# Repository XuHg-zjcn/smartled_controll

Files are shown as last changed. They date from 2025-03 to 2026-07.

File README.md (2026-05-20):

# 智能LED控制器
该LED控制器用于吸顶灯、灯带、台灯的控制，使用12-48V电源供电(使用Buck驱动，电源电压必须高于灯的电压)，使用经过编码的RS485通信。计划PCB采用双面板，板上最多可焊4个LED驱动电路
待添加多种设计，分别支持4通道和2通道
需要添加外接声感（驻极体麦克风），雷达，（热释电）红外线等传感器检测下亮灯

经过平衡安全性、稳定性、传输效率、可扩展性、总成本等因素的考量，我设计家庭小功率电器总线采用不超过直流60V的SELV供电。使用两根直流电源线（不接地）和一对差分通信线。  
为了防止通信线(RS485)误接电源线造成过压等原因导致芯片等元器件损坏，我参考网上资料设计了一套保护电路。其中甚至牺牲了一些兼容性，让数据经过直流平衡的编码后再传输，这样信号能顺利通过电容，误接直流电时后面电路只有一个脉冲，大大减轻TVS管负荷。  

# 主要元器件列表
|  名称  | 型号 | 参数 |
|:---:|:---|:---|
|MCU |候选PY32F003F1|QFN20封装 |
|DCDC转换|OC5864 |最高60V输入, 0.6A|
|LED驱动 |OC5028B/OC5020B|100V 1.2A/2A|
|通信芯片|候选MAX485 |最高2.5Mbps  |

其他元器件请通过KiCAD生成BOM表获取

# 构建PCB工程
为了减少git仓库占用空间，我在`git commit`提交前在KiCad中清除所有填充域(快捷键Ctrl+B)，您可以在打开后重新填充(快捷键B)
在KiCad的Python控制台中，切换到该repo根目录运行下例命令
````python
import build
build.all()
```
即可自动完成添加泪滴、重新填充、应用PCB背面信息字符串

# 版权和许可证
Copyright (C) 2025  徐瑞骏  
本设计以CERN开放硬件许可证第二版强互惠授权(CERN Open Hardware Licence Version 2 - Strongly Reciprocal)，许可证文件位于`cern_ohl_s_v2.txt`  
本设计不提供任何保证

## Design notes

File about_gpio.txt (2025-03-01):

LED驱动器 PY32F003F1xUx主控管脚配置

         可用管脚(晶振脚保留)
TIM1_CH1 PA3
TIM1_CH2 PA13
TIM1_CH3 PA0 PB6
TIM1_CH4 PA1

I2C_SDA PA12 PA2 PA7 PB7
I2C_SCL PA3 PB6

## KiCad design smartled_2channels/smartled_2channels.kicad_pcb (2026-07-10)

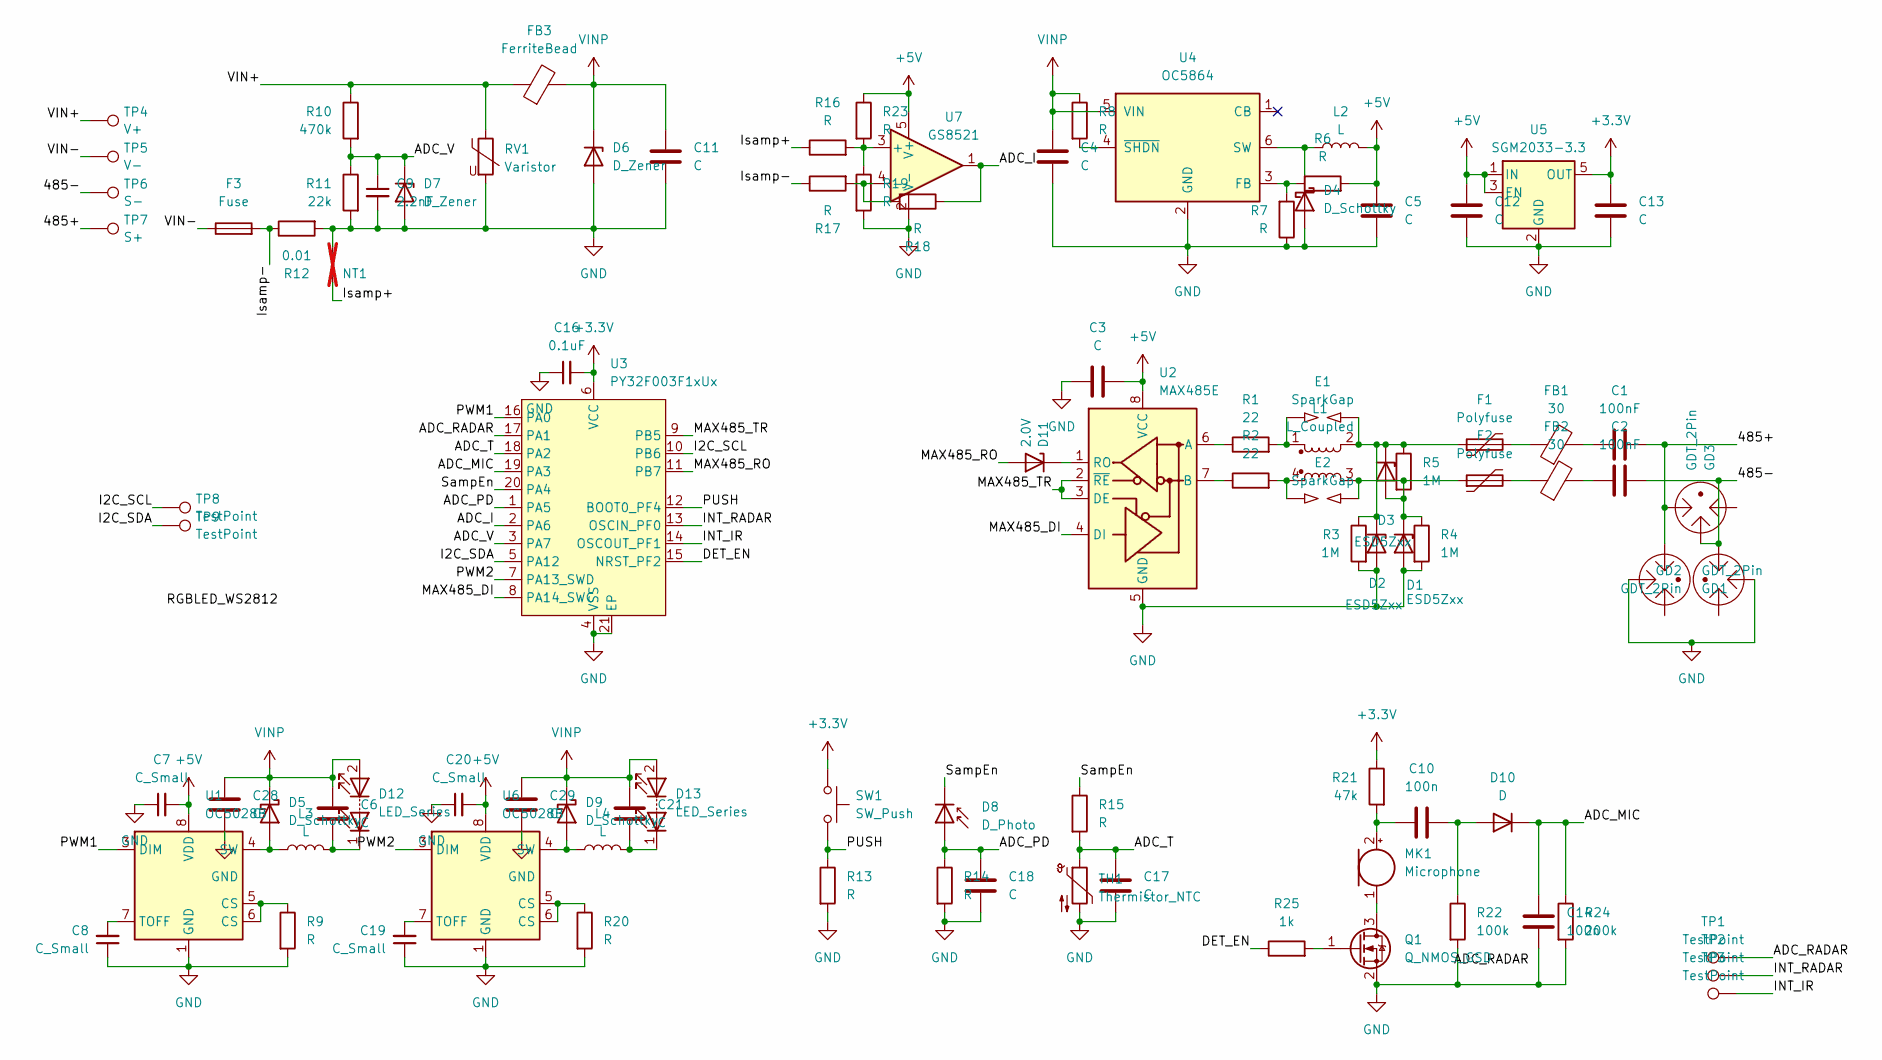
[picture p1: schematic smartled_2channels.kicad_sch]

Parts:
C1, C2: 100nF; C_0603_1608Metric
C3: C; C_0603_1608Metric
C4, C5, C12, C13: C; C_0805_2012Metric
C6, C11, C21, C28, C29: C; C_1210_3225Metric
C7, C8, C19, C20: C_Small; C_0402_1005Metric
C9: 2.2nF; C_0603_1608Metric
C10, C14: 100n; C_0402_1005Metric
C16: 0.1uF; C_0603_1608Metric
C17, C18: C; C_0402_1005Metric
D1, D2, D3: ESD5Zxx; D_SOD-523
D4: D_Schottky; D_SOD-123F
D5, D9: D_Schottky; D_SMA
D6: D_Zener; D_SMA
D7: D_Zener; D_SOD-323
D8: D_Photo; D_0805_2012Metric
D10: D; D_SOD-523
D11: 2.0V; D_SOD-523
D12, D13: LED_Series; 2Pads_1.5x2.7mm_Tshape_mpsign
E1, E2: SparkGap
F1, F2: Polyfuse; Fuse_0603_1608Metric
F3: Fuse; Fuse_1206_3216Metric
FB1, FB2: 30; L_0603_1608Metric
FB3: FerriteBead; L_1210_3225Metric
GD1, GD2, GD3: GDT_2Pin; C_1206_3216Metric
L1: L_Coupled; L_CommonModeChoke_Coilcraft_1812CAN
L2: L; L_1210_3225Metric
L3, L4: L; L_APV_APH0630
MK1: Microphone; D_SOD-323
NT1: NetTie_2; NetTie-2_VIA_Pad0.6_0.3mm; not fitted
Q1: Q_NMOS_GSD; SOT-23
R1, R2: 22; R_0603_1608Metric
R3, R4, R5: 1M; R_0603_1608Metric
R6, R7, R8, R13, R14, R15, R16, R17, R18, R19, R23: R; R_0402_1005Metric
R9, R20: R; R_1206_3216Metric
R10: 470k; R_0603_1608Metric
R11: 22k; R_0603_1608Metric
R12: 0.01; R_1206_3216Metric
R21: 47k; R_0402_1005Metric
R22: 100k; R_0603_1608Metric
R24: 200k; R_0402_1005Metric
R25: 1k; R_0402_1005Metric
RV1: Varistor; R_1206_3216Metric
SW1: SW_Push; SW_Push_SPST_NO_Alps_SKRK
TH1: Thermistor_NTC; R_0805_2012Metric
TP1, TP2, TP3, TP8, TP9: TestPoint; 1Pad_0.6mm
TP4: V+; TestPoint_THTPad_D1.0mm_Drill0.5mm
TP5: V-; TestPoint_THTPad_D1.0mm_Drill0.5mm
TP6: S-; TestPoint_THTPad_D1.0mm_Drill0.5mm
TP7: S+; TestPoint_THTPad_D1.0mm_Drill0.5mm
U1, U6: OC5028B; HSOP-8-1EP_3.9x4.9mm_P1.27mm_EP2.41x3.1mm_ThermalVias_0.3_0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
U2: MAX485E; SOIC-8_3.9x4.9mm_P1.27mm
U3: PY32F003F1xUx; QFN-20-1EP_3x3mm_P0.4mm_EP1.65x1.65mm
U4: OC5864; SOT-23-6
U5: SGM2033-3.3; SOT-23-5
U7: GS8521; TSOT-23-5

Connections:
+3.3V: C13.1, C16.2, R21.1, SW1.1, U3.6 (VCC), U5.5 (OUT)
+5V: C3.2, C5.1, C7.2, C12.1, C20.2, L2.2, R6.2, R23.1, U1.8 (VDD), U2.8 (VCC), U5.1 (IN), U5.3 (EN), U6.8 (VDD), U7.5 (V+)
/485+: C1.2, GD1.1, GD3.1, TP7.1
/485-: C2.2, GD2.1, GD3.2, TP6.1
/ADC_I: R18.1, U3.2 (PA6), U7.1
/ADC_MIC: C14.1, D10.1 (K), R24.1, U3.19 (PA3)
/ADC_PD: C18.1, D8.2 (A), R14.1, U3.1 (PA5)
/ADC_RADAR: TP1.1, U3.17 (PA1)
/ADC_T: C17.1, R15.2, TH1.1, U3.18 (PA2)
/ADC_V: C9.1, D7.1 (K), R10.2, R11.1, U3.3 (PA7)
/DET_EN: R25.1, U3.15 (NRST_PF2)
/I2C_SCL: TP8.1, U3.10 (PB6)
/I2C_SDA: TP9.1, U3.5 (PA12)
/INT_IR: TP3.1, U3.14 (OSCOUT_PF1)
/INT_RADAR: TP2.1, U3.13 (OSCIN_PF0)
/Isamp+: NT1.2, R16.1
/Isamp-: F3.2, R12.1, R17.1
/MAX485_DI: U2.4 (DI), U3.8 (PA14_SWC)
/MAX485_RO: D11.2 (A), U3.11 (PB7)
/MAX485_TR: U2.2 (~RE), U2.3 (DE), U3.9 (PB5)
/PUSH: R13.1, SW1.2, U3.12 (BOOT0_PF4)
/PWM1: U1.3 (DIM), U3.16 (PA0)
/PWM2: U3.7 (PA13_SWD), U6.3 (DIM)
/SampEn: D8.1 (K), R15.1, U3.20 (PA4)
/VIN+: FB3.1, R10.1, RV1.1, TP4.1
/VIN-: F3.1, TP5.1
GND: C3.1, C4.1, C5.2, C7.1, C8.1, C9.2, C11.2, C12.2, C13.2, C14.2, C16.1, C17.2, C18.2, C19.1, C20.1, C28.1, C29.1, D1.2 (A), D2.2 (A), D4.2 (A), D6.2 (A), D7.2 (A), GD1.2, GD2.2, NT1.1, Q1.2 (S), R3.2, R4.2, R7.1, R9.2, R11.2, R12.2, R13.2, R14.2, R19.2, R20.2, R22.2, R24.2, RV1.2, TH1.2, U1.1 (GND), U2.5 (GND), U3.4 (VSS), U3.21 (EP), U4.2 (GND), U5.2 (GND), U6.1 (GND), U7.2 (V-)
unnamed: C1.1, FB1.2
unnamed: C2.1, FB2.2
unnamed: D1.1 (K), D3.2 (A), E2.2, F2.1, L1.3, R4.1, R5.2
unnamed: D2.1 (K), D3.1 (K), E1.2, F1.1, L1.2, R3.1, R5.1
unnamed: D4.1 (K), L2.1, U4.6 (SW)
unnamed: D5.2 (A), L3.1, U1.4 (SW), U1.9 (EP)
unnamed: D9.2 (A), L4.1, U6.4 (SW), U6.9 (EP)
unnamed: C10.2, D10.2 (A), R22.1
unnamed: D11.1 (K), U2.1 (RO)
unnamed: C6.2, D12.1 (K), L3.2
unnamed: C21.2, D13.1 (K), L4.2
unnamed: E1.1, L1.1, R1.2
unnamed: E2.1, L1.4, R2.2
unnamed: F1.2, FB1.1
unnamed: F2.2, FB2.1
unnamed: C10.1, MK1.2 (+), R21.2
unnamed: MK1.1 (-), Q1.3 (D)
unnamed: Q1.1 (G), R25.2
unnamed: R9.1, U1.5 (CS), U1.6 (CS)
unnamed: R20.1, U6.5 (CS), U6.6 (CS)
unnamed: C8.2, U1.7 (TOFF)
unnamed: R1.1, U2.6 (A)
unnamed: R2.1, U2.7 (B)
unnamed: R6.1, R7.2, U4.3 (FB)
unnamed: R8.2, U4.4 (~SHDN)
unnamed: C19.2, U6.7 (TOFF)
unnamed: R16.2, R19.1, R23.2, U7.3 (+)
unnamed: R17.2, R18.2, U7.4 (-)
VINP: C4.2, C6.1, C11.1, C21.1, C28.2, C29.2, D5.1 (K), D6.1 (K), D9.1 (K), D12.2 (A), D13.2 (A), FB3.2, R8.1, U4.5 (VIN)

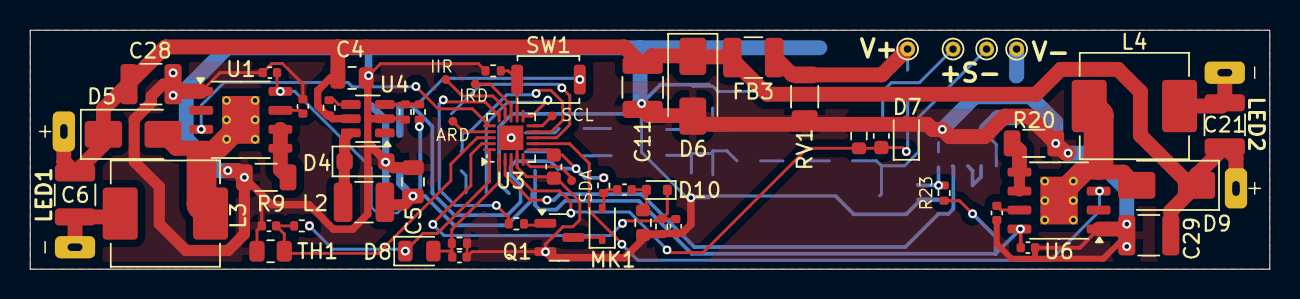
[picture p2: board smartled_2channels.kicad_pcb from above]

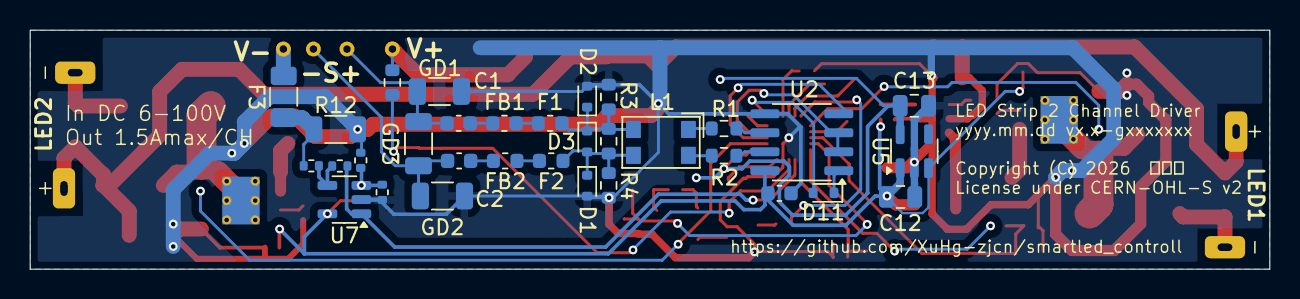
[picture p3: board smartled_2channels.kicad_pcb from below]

Board: 2 copper layers, 83.0 x 16.0 mm, 94 parts (32 on the bottom side), 55 nets.

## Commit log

2025-02-23 添加README.md和CERN-OHL-S许可证
2025-02-23 单片机换为PY32F003F1xUx（自己制作符号），添加3.3V LDO电路，电流采样放大电路，按键，温度和光照传感器
    [smartled_controll.kicad_sch]
2025-02-24 在PCB上放置各电路模块的元器件大致布局，少量修改原理图
    [smartled_controll.kicad_pcb, smartled_controll.kicad_sch]
2025-02-25 布线和调整布局，把PCB上的电路按模块分组
    [smartled_controll.kicad_pcb, smartled_controll.kicad_sch]
2025-02-26 复制LED驱动模块为4个
    [smartled_controll.kicad_pcb, smartled_controll.kicad_sch]
2025-02-26 布线和微调布局（除光电二极管和温度传感器外）
    [smartled_controll.kicad_pcb, smartled_controll.kicad_sch]
2025-02-27 调整布局，划出PCB边框，MCU连接光电二极管和温度传感器
    [smartled_controll.kicad_pcb, smartled_controll.kicad_sch]
2025-02-27 添加GND,VINP等覆铜（提交前已清除填充来减小文件大小，请在KiCAD重新填充）
    [smartled_controll.kicad_pcb]
2025-02-27 修复DRC错误，调整位号等
    [smartled_controll.kicad_pcb]
2025-03-01 添加LED驱动输入滤波电容(1210封装)
    [smartled_controll.kicad_pcb, smartled_controll.kicad_sch]
2025-03-01 添加I2C接口
    [smartled_controll.kicad_pcb, smartled_controll.kicad_sch]
2025-03-01 按照数据手册将PY32中心焊盘接GND
    [smartled_controll.kicad_pcb, smartled_controll.kicad_sch]
2025-03-02 PCB上添加接口定义和版权声明文本
    [smartled_controll.kicad_pcb]
2025-03-02 按OC5028B数据手册将第二脚NC改成不连接
    [smartled_controll.kicad_pcb, smartled_controll.kicad_sch]
2025-03-09 在RS485的两条差分线间再添加一个气体放电管，都改为1206封装
    [smartled_controll.kicad_pcb, smartled_controll.kicad_sch]
2025-03-10 保险丝改成2410(6125)封装
    [smartled_controll.kicad_pcb, smartled_controll.kicad_sch]
2025-03-10 选择3.3V LDO和电流采样运放的型号
    [smartled_controll.kicad_pcb, smartled_controll.kicad_sch]
2025-03-10 添加LED接口焊盘
    [smartled_controll.kicad_pcb, smartled_controll.kicad_sch]
2025-03-10 添加LED接口编号丝印
    [smartled_controll.kicad_pcb]
2025-03-12 优化3D图效果：隐藏借用footprint而产生不正确的3D模型
    [smartled_controll.kicad_pcb]
2025-03-12 PCB上添加说明文本，从其他工程复制build.py脚本
    [smartled_controll.kicad_pcb]
2025-04-29 提交遗留内容，添加圆角和安装孔
    [smartled_controll.kicad_pcb]
2025-04-29 设置PCB工程的最小间距、最小走线宽度和最小连接宽度，最小线宽改成0.16mm
    [smartled_controll.kicad_pcb]
2026-05-20 现有工程移动移动到4channels目录下，更新README.md
    [smartled_controll.kicad_pcb, smartled_controll.kicad_sch]
2026-05-20 添加2通道驱动器工程，从4通道驱动器复制部分内容并进行大致布局
    [smartled_2channels.kicad_pcb, smartled_2channels.kicad_sch]
2026-05-20 添加麦克风声感应电路，红外和雷达传感器接口
    [smartled_2channels.kicad_pcb, smartled_2channels.kicad_sch]
2026-05-22 压缩布局至85.4x16mm尺寸
    [smartled_2channels.kicad_pcb]
2026-05-24 进行布线，微调原理图
    [smartled_2channels.kicad_pcb, smartled_2channels.kicad_sch]
2026-05-26 连接一些未连接项目
    [smartled_2channels.kicad_pcb]
2026-05-29 修改LED输出焊盘，缩短PCB长度到83mm
    [smartled_2channels.kicad_pcb, smartled_2channels.kicad_sch]
2026-05-30 修改丝印
    [smartled_2channels.kicad_pcb]
2026-05-30 修复一些DRC错误，优化布线
    [smartled_2channels.kicad_pcb, smartled_2channels.kicad_sch]
2026-05-30 电源和通信端口放置通孔焊盘用于焊接电线
    [smartled_2channels.kicad_pcb, smartled_2channels.kicad_sch]
2026-05-31 修改TP焊盘为0.6mm，引出I2C接口
    [smartled_2channels.kicad_pcb, smartled_2channels.kicad_sch]
2026-05-31 保险丝移动到负极
    [smartled_2channels.kicad_pcb, smartled_2channels.kicad_sch]
2026-05-31 修改LED输出接口为通孔焊盘
    [smartled_2channels.kicad_pcb]
2026-06-07 MAX485 RO添加稳压二极管做电平转换
    [smartled_2channels.kicad_pcb, smartled_2channels.kicad_sch, smartled_controll.kicad_pcb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]
2026-07-10 按照OC5028B数据手册，散热焊接与SW引脚连接 修复Out-与In-短路问题，已有PCB在散热焊盘涂阻焊油处理
    [smartled_2channels.kicad_pcb, smartled_2channels.kicad_sch, smartled_controll.kicad_pcb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]
2026-07-10 加宽散热走线
    [smartled_2channels.kicad_pcb, smartled_controll.kicad_pcb]
2026-07-10 优化走线
    [smartled_2channels.kicad_pcb]

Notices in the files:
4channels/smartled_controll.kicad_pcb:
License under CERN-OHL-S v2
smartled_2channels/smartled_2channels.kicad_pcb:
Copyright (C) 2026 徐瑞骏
